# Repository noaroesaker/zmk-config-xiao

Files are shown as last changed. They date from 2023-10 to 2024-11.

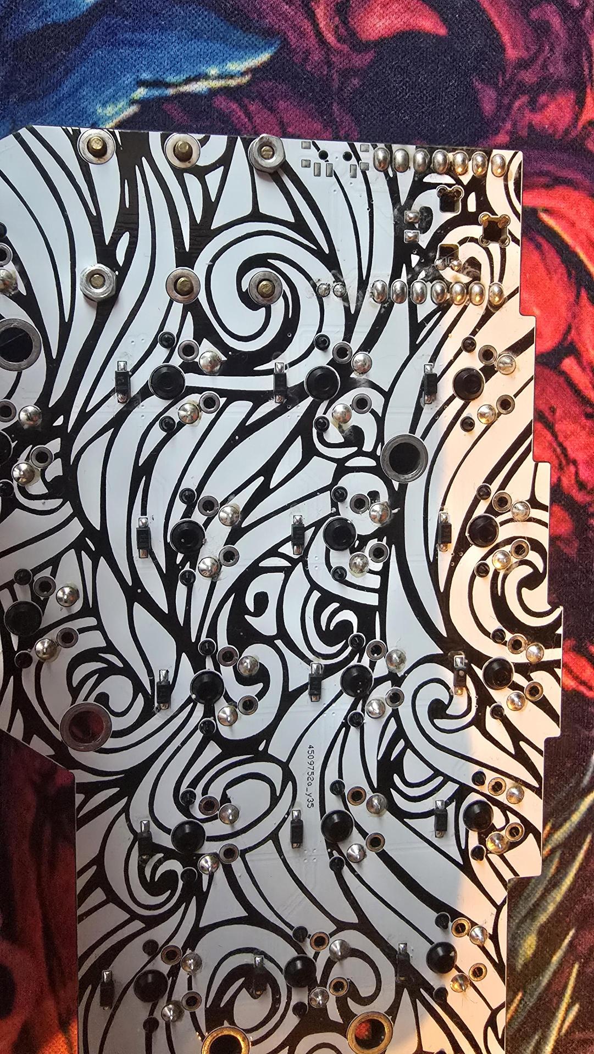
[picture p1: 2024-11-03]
Media(1).jpeg

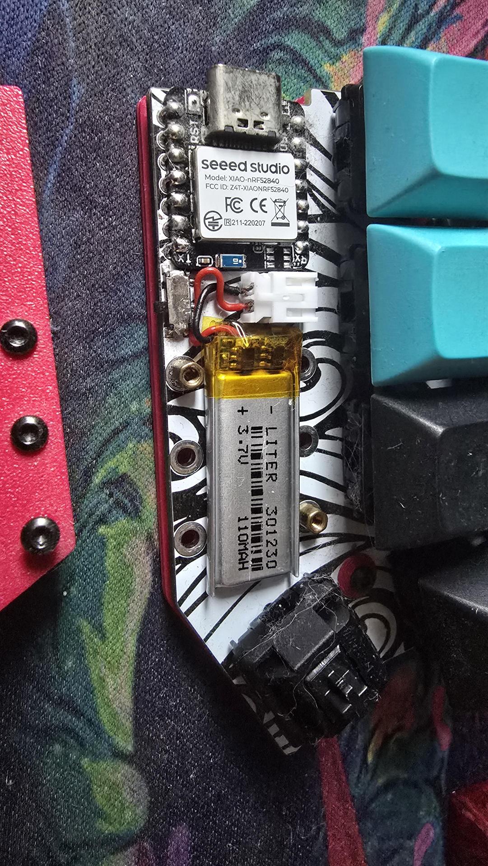
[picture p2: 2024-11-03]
Media.jpeg

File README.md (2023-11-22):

# zmk_corne

This project would not be possible without the help of these people:
https://github.com/makgyber/kiai-split
https://github.com/wj-zhe/Kretstrad
or most importantly:
https://github.com/alexpantiukhin/zmk-config-xiao
This one helped me figure out the layout for the files i need to make the firmware compile. It is modified, but the core of this persons work is still there, so thanks.

But lets not forget the best layout for custom keyboards :)
https://github.com/foostan/crkbd

And also the youtubers who helped me understand:
https://www.youtube.com/@joe_scotto
https://www.youtube.com/@SethusBuilds
https://www.youtube.com/@BenVallacksKeyboards
https://www.youtube.com/@BenVallack

This corne like build features a Xiao BLE controller and a custom designed board designed by me, but heavily inspired by the crkbd.
The wiring based on how the kiai split does it to keep both controllers up side but not use multiple pads like the older cornes or the helix

KiCad project is a redesigned corne choc, but everything is changed except the general outline. Files in this repository

The PCB did work, but there is some clearance issues with the power switch and the controller, so that will be changed in the kicad folder.

battery test:
10 nov 22:53:31 L = 3,89V R = 3,89V
+ 10:45 (battery connected) =
11 nov 09:46:10 L = 3,85V R = 3,86V
+ 02:30 (youtube usage) =
11 nov 12:15:10 L = 3,84V R = 3,85V
+ 01:30 (youtube and 10 min osu) =
11 nov 13:42:30 L = 3,83V R = 3,84V
+ 10:00 (disconnect battery) =
12 nov 11:48:30 L = 3,83V R = 3,85V
+ 08:45 (youtube usage) =
12 nov 20:27:30 L = 3,79V R = 3,82V

avrg loss
  L = 0,004V/h
  R = 0,003V/h

estimated battery life (4,1V - 3,2V = 0,9V)
  L = 0,9V / 0,004V = 225h = 9 days
  R = 0,9V / 0,003V = 300h = 12 days

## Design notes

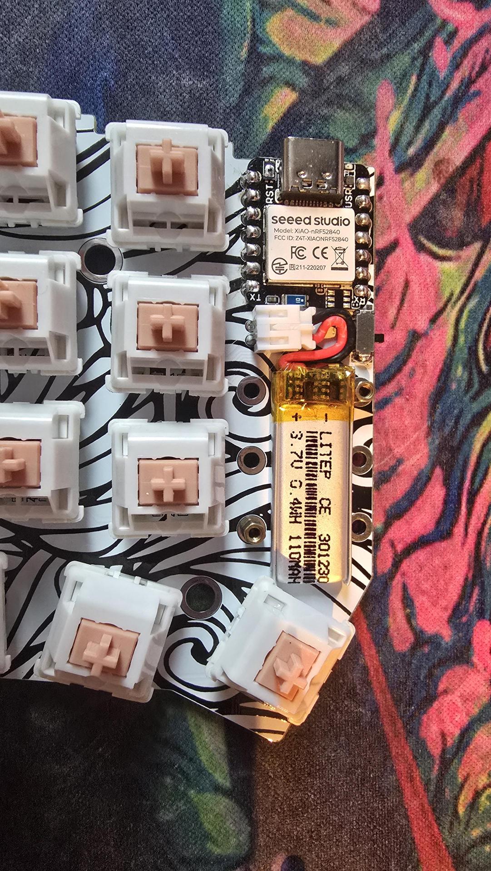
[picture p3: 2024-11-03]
Media(2).jpeg

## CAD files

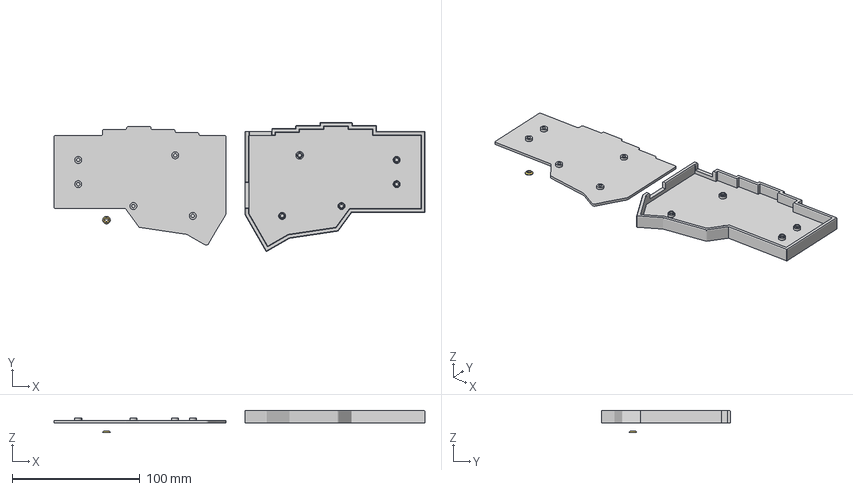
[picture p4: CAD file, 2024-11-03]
case files/corne_low_profile_case.3mf
290.8 x 101.1 x 17.4 mm
sandwitch case
low_profile_case v14
screw spacer

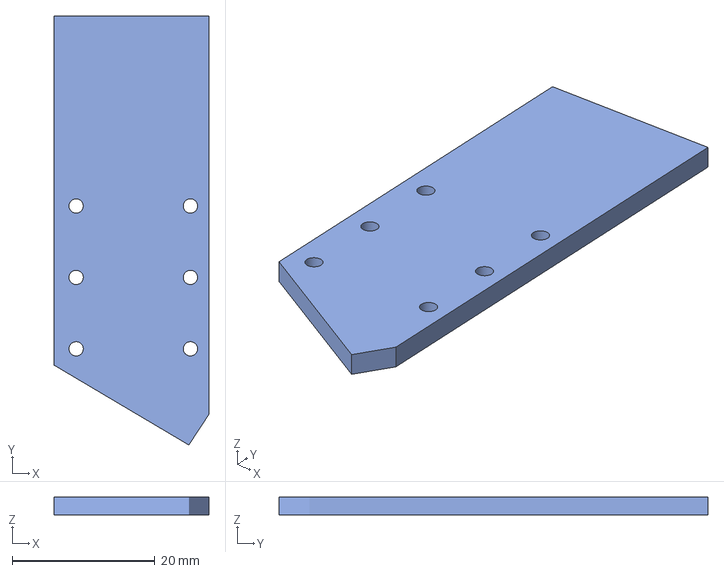
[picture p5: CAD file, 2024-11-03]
case files/batteryplate.3mf
21.7 x 60.1 x 2.50 mm

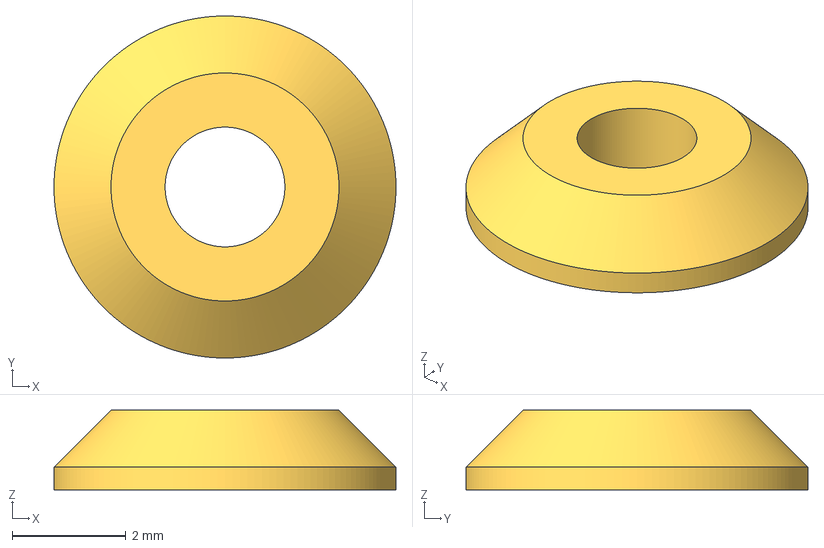
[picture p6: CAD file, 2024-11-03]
case files/screw spacer.3mf
6.00 x 6.00 x 1.40 mm

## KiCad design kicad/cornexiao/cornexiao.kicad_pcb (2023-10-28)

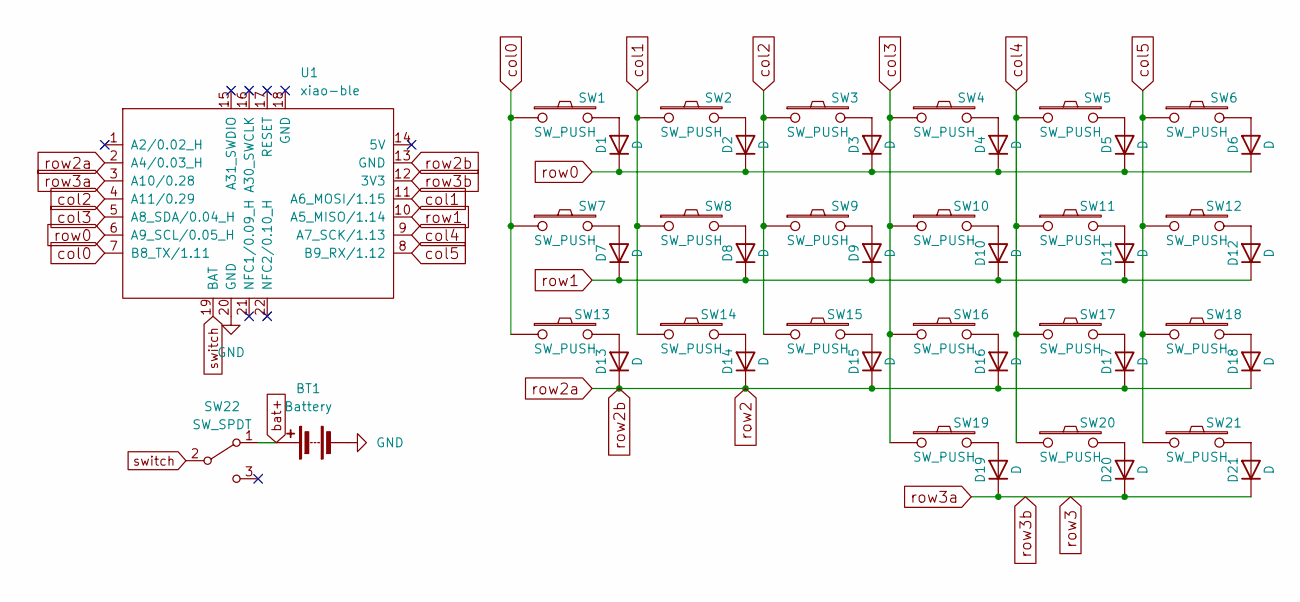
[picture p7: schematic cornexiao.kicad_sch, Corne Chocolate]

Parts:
BT1: Battery
D1, D2, D3, D4, D5, D6, D7, D8, D9, D10, D11, D12, D13, D14, D15, D16, D17, D18, D19, D20, D21: D; D3_TH_SMD
SW1, SW2, SW3, SW4, SW5, SW6, SW7, SW8, SW9, SW10, SW11, SW12, SW13, SW14, SW15, SW16, SW17, SW18, SW19, SW20, SW21: SW_PUSH; MX_ALPS_PG1350_noLed
SW22: SW_SPDT; SW_SPDT_PCM12
U1: xiao-ble; xiao-ble-smd-cutout

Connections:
GND: BT1.2 (-), U1.20 (GND)
unnamed: D1.2 (A), SW1.2
unnamed: D2.2 (A), SW2.2
unnamed: D3.2 (A), SW3.2
unnamed: D4.2 (A), SW4.2
unnamed: D5.2 (A), SW5.2
unnamed: D6.2 (A), SW6.2
unnamed: D7.2 (A), SW7.2
unnamed: D8.2 (A), SW8.2
unnamed: D9.2 (A), SW9.2
unnamed: D10.2 (A), SW10.2
unnamed: D11.2 (A), SW11.2
unnamed: D12.2 (A), SW12.2
unnamed: D13.2 (A), SW13.2
unnamed: D14.2 (A), SW14.2
unnamed: D15.2 (A), SW15.2
unnamed: D16.2 (A), SW16.2
unnamed: D17.2 (A), SW17.2
unnamed: D18.2 (A), SW18.2
unnamed: D19.2 (A), SW19.2
unnamed: D20.2 (A), SW20.2
unnamed: D21.2 (A), SW21.2
bat+: BT1.1 (+), SW22.1 (A); also elsewhere on the board
col0: SW1.1, SW7.1, SW13.1, U1.7 (B8_TX/1.11)
col1: SW2.1, SW8.1, SW14.1, U1.11 (A6_MOSI/1.15)
col2: SW3.1, SW9.1, SW15.1, U1.4 (A11/0.29)
col3: SW4.1, SW10.1, SW16.1, SW19.1, U1.5 (A8_SDA/0.04_H)
col4: SW5.1, SW11.1, SW17.1, SW20.1, U1.9 (A7_SCK/1.13)
col5: SW6.1, SW12.1, SW18.1, SW21.1, U1.8 (B9_RX/1.12)
row0: D1.1 (K), D2.1 (K), D3.1 (K), D4.1 (K), D5.1 (K), D6.1 (K), U1.6 (A9_SCL/0.05_H)
row1: D7.1 (K), D8.1 (K), D9.1 (K), D10.1 (K), D11.1 (K), D12.1 (K), U1.10 (A5_MISO/1.14)
row2: D13.1 (K), D14.1 (K), D15.1 (K), D16.1 (K), D17.1 (K), D18.1 (K), U1.2 (A4/0.03_H), U1.13 (GND); also elsewhere on the board
row3: D19.1 (K), D20.1 (K), D21.1 (K), U1.3 (A10/0.28), U1.12 (3V3); also elsewhere on the board
switch: SW22.2 (B), U1.19 (BAT); also elsewhere on the board

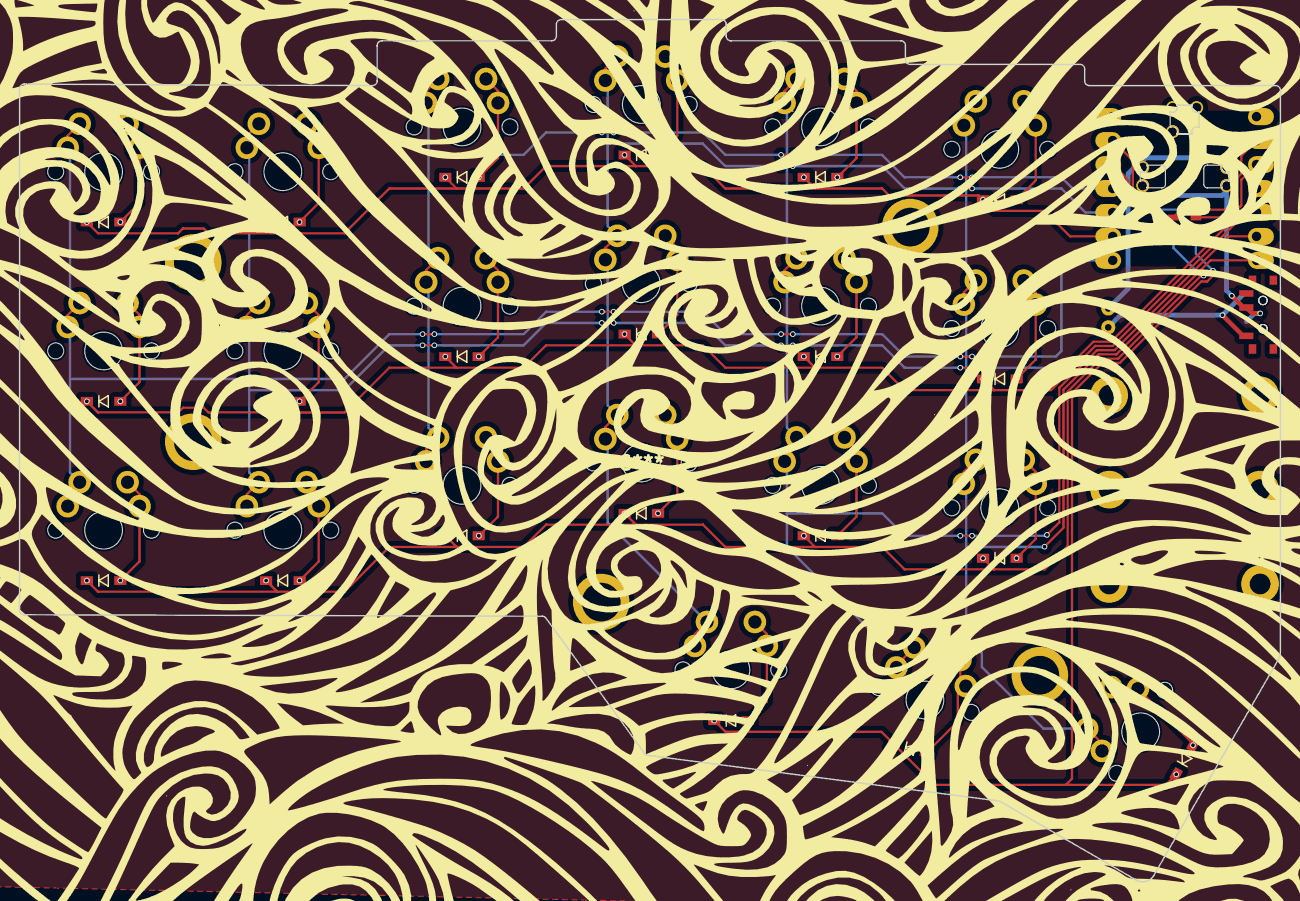
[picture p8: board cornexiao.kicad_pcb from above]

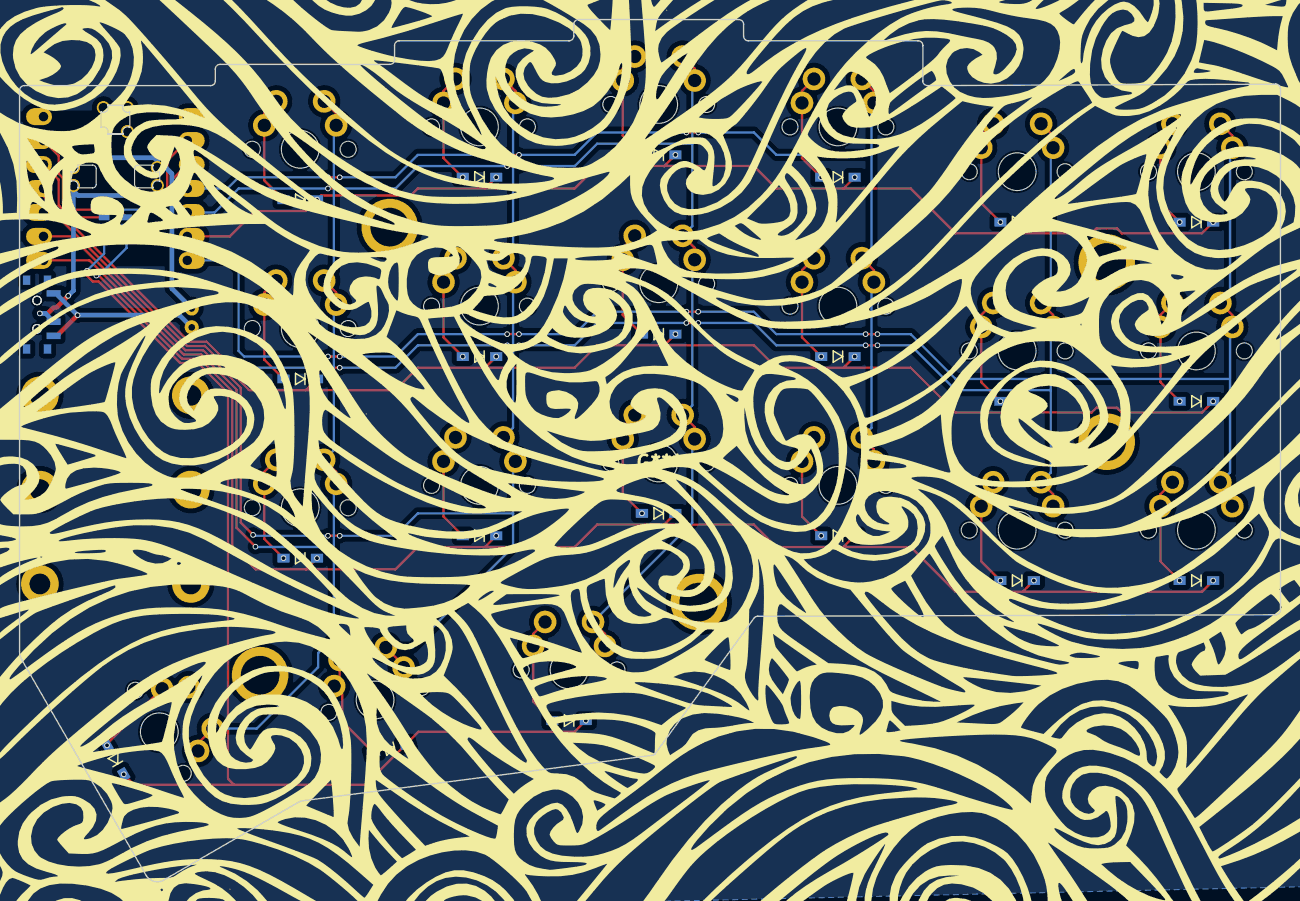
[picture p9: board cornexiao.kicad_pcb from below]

Board: 2 copper layers, 133.7 x 91.4 mm, 49 parts (3 on the bottom side), 33 nets.

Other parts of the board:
JP5, JP5#2, JP5#3, JP5#4: Jumper
SW22#2: SW_SPDT; SW_SPDT_PCM12

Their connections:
bat+: SW22#2.1 (A); also elsewhere on the board
row2: JP5.1, JP5.2, JP5#3.1, JP5#3.2; also elsewhere on the board
row3: JP5#2.1, JP5#2.2, JP5#4.1, JP5#4.2; also elsewhere on the board
switch: SW22#2.2 (B); also elsewhere on the board

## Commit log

2023-10-28 forgot renaming board folder
2023-10-28 ordered pcb files
    [corne-chocolate-B_Cu.gbr, corne-chocolate-B_Mask.gbr, corne-chocolate-B_Silkscreen.gbr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]
2023-10-28 updated file structure
    [batteryholder.3mf, cherry_switch_plate.3mf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]
2023-11-11 battery tests before testing disconnected state
2024-01-14 changed layer change routes and added trans under landing zones
2024-11-03 pics and shii
    [batteryholder.3mf, batteryplate.3mf, cherry_switch_plate.3mf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]
2024-11-03 last case file
    [screw spacer.3mf]
